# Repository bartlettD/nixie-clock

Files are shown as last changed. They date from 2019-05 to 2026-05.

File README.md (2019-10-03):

# nixie-clock
A Nixie Tube based clock. Because everyone has to play with Nixies once, right?

## Introduction

The goal of this project is to design and contstruct a simple 4/6-Digit clock based around a set of [IN-12B Nixie Tubes](https://en.wikipedia.org/wiki/Nixie_tube). They are a type of cold-cathode display neon readout tube invented in the 1950's and used commonly in the USSR in volume manufacture until the 1980's after the rest of the world had moved on to 7-Segment LED arrays and other indicator technologies.

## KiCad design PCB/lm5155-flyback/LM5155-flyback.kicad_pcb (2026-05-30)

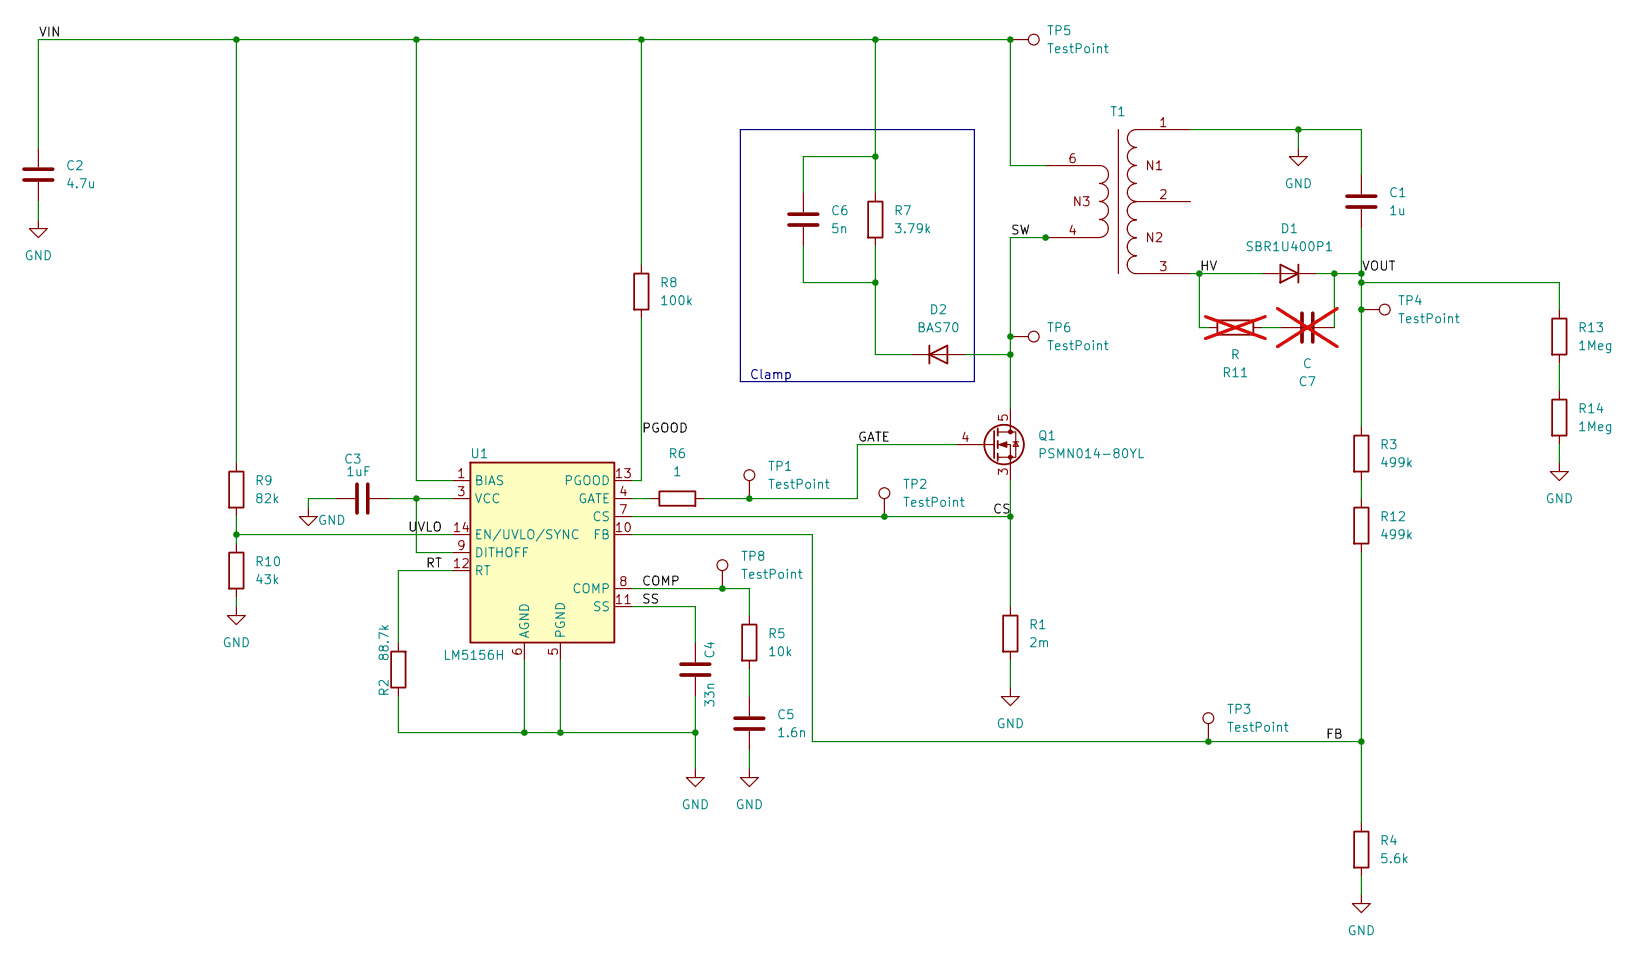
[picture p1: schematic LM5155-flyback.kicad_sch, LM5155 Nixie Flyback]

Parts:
C1: 1u; C_2220_5750Metric_Pad1.97x5.40mm_HandSolder
C2: 4.7u; C_0805_2012Metric_Pad1.18x1.45mm_HandSolder
C3: 1uF; C_0805_2012Metric_Pad1.18x1.45mm_HandSolder
C4: 33n; C_0805_2012Metric_Pad1.18x1.45mm_HandSolder
C5: 1.6n; C_0805_2012Metric_Pad1.18x1.45mm_HandSolder
C6: 5n; C_0805_2012Metric_Pad1.18x1.45mm_HandSolder
C7: C; C_0805_2012Metric_Pad1.18x1.45mm_HandSolder; not fitted
D1: SBR1U400P1; D_PowerDI-123
D2: BAS70; SOT-23
Q1: PSMN014-80YL; LFPAK56
R1: 2m; R_0805_2012Metric_Pad1.20x1.40mm_HandSolder
R2: 88.7k; R_0805_2012Metric_Pad1.20x1.40mm_HandSolder
R3, R12: 499k; R_0805_2012Metric_Pad1.20x1.40mm_HandSolder
R4: 5.6k; R_0805_2012Metric_Pad1.20x1.40mm_HandSolder
R5: 10k; R_0805_2012Metric_Pad1.20x1.40mm_HandSolder
R6: 1; R_0805_2012Metric_Pad1.20x1.40mm_HandSolder
R7: 3.79k; R_0805_2012Metric_Pad1.20x1.40mm_HandSolder
R8: 100k; R_0805_2012Metric_Pad1.20x1.40mm_HandSolder
R9: 82k; R_0805_2012Metric_Pad1.20x1.40mm_HandSolder
R10: 43k; R_0805_2012Metric_Pad1.20x1.40mm_HandSolder
R11: R; R_0805_2012Metric_Pad1.20x1.40mm_HandSolder; not fitted
R13, R14: 1Meg; R_0805_2012Metric_Pad1.20x1.40mm_HandSolder
T1: EP7-5801_750315825; T_Wurth_WE-FLYLT-EP7-5801; Part Number 750315825
TP1, TP2, TP3, TP4, TP5, TP6, TP8: TestPoint; TestPoint_Keystone_5019_Miniature
U1: LM5156H; Texas_HTSSOP-14-1EP_4.4x5mm_P0.65mm_EP3.4x5mm_Mask3.155x3.2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

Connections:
/COMP: R5.1, TP8.1 (1_1), U1.8 (COMP)
/CS: Q1.1 (S), Q1.2 (S), Q1.3 (S), R1.1, TP2.1 (1_1), U1.7 (CS)
/FB: R4.1, R12.2, TP3.1 (1_1), U1.10 (FB)
/GATE: Q1.4 (G), R6.2, TP1.1 (1_1)
/HV: D1.2 (A), R11.1, T1.3
/PGOOD: R8.2, U1.13 (PGOOD)
/RT: R2.2, U1.12 (RT)
/SS: C4.1, U1.11 (SS)
/SW: D2.1 (A), Q1.5 (D), T1.4, TP6.1 (1_1)
/UVLO: R9.2, R10.1, U1.14 (EN/UVLO/SYNC)
/VIN: C2.1, C6.1, R7.1, R8.1, R9.1, T1.6, TP5.1 (1_1), U1.1 (BIAS)
/VOUT: C1.2, C7.1, D1.1 (K), R3.1, R13.1, TP4.1 (1_1)
GND: C1.1, C2.2, C3.1, C4.2, C5.2, R1.2, R2.1, R4.2, R10.2, R14.2, T1.1, U1.5 (PGND), U1.6 (AGND), U1.15 (AGND)
unnamed: C5.1, R5.2
unnamed: C7.2, R11.2
unnamed: C6.2, D2.3 (K), R7.2
unnamed: R3.2, R12.1
unnamed: R13.2, R14.1
unnamed: C3.2, U1.3 (VCC), U1.9 (DITHOFF)
unnamed: R6.1, U1.4 (GATE)

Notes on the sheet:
Clamp

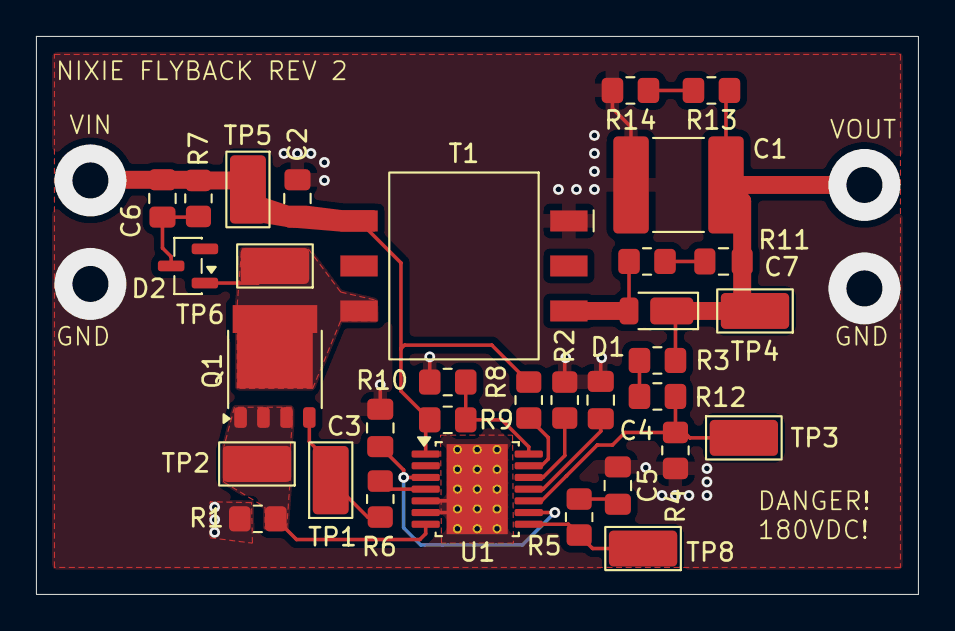
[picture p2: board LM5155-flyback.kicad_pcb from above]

Board: 2 copper layers, 49.0 x 31.0 mm, 33 parts (0 on the bottom side), 20 nets.

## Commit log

2019-05-27 Adding rough simulation of a charge-pump multiplied Boost Circuit
2019-05-27 Starting on PCB, creating IN12-B footprint
    [nixie-clock.kicad_pcb, nixie-clock.sch]
2019-05-28 Add Charge Pump Doubler Simulation
2019-05-29 Improved charge pump circuit
2019-06-03 Introduced Ideal FET and Diode for testing
2019-10-02 Adding spreadsheet to hold calculations for converter
    [BoostCalcs.ods]
2019-10-03 Fixed Symbol library path and Feedback Resistors
    Fixed the LM3478 symbol to point to a .lib within the current directory
    rather than in my own home directory. Makes cloning and running the sims
    on a new computer much easier.
    Fixed the parameter calculation for feedback resistors.
2019-10-03 Doing some calcs for Boost Converter
    [BoostCalcs.ods]
2020-11-12 Work on some Boost Converter calculations
    [BoostCalcs.ods]
2020-11-13 Calculate inductance values vs frequency
    [BoostCalcs.ods]
2020-11-14 Further Boost Converter Calculations
    [BoostCalcs.ods]
2020-11-15 Develop calculation further. Replace ods with fods for better version tracking
    [BoostCalcs.ods]
2020-11-15 Start calculating RMS currents
2020-11-19 Calculate RMS currents for switch, diode, inductor.
2021-07-11 Add simple diode loss calculation
2021-07-13 Inductor resistive losses and calculate total efficieny over inductance vs. frequency
2021-07-24 Trying out sim in KiCad.
    [nixie-clock.sch]
2021-08-08 Add charge pump to Nixie concept
2026-01-13 Rework .gitignore so I can use pspice
    [nixie-clock.kicad_pcb, nixie-clock.sch]
2026-01-13 directory cleanup
    [nixie-clock.kicad_pcb, nixie-clock.sch]
2026-01-15 Flyback pspice simulations
    [flyback.dsn]
2026-01-15 Updated flyback calculations, further flyback simulation
    [flyback.dsn]
2026-01-16 Tidy up FET table
2026-01-17 Add another FET
2026-01-17 TPS40210 converter appears to be working. Still need to properly compensate the control loop
    [flyback.dsn]
2026-01-27 Looking at an LM5155 based converter. Current-mode control is attractive
    [flyback.dsn]
2026-01-28 More simulation. Import WIP LM5155 schematic
    [LM5155-flyback.kicad_pcb, LM5155-flyback.kicad_sch, flyback.dsn]
2026-02-02 Started flyback layout and tweak simulations
    [LM5155-flyback.kicad_pcb, LM5155-flyback.kicad_sch, flyback.dsn]
2026-02-02 More flyback layout. Almost done!
    [LM5155-flyback.kicad_pcb, LM5155-flyback.kicad_sch]
2026-02-03 Layout done. Send to fabricate
    [LM5155-flyback.kicad_pcb]
2026-02-03 Fix small issue with feedback resistors. Hopefully wont cause real issues with Rev 1
    [LM5155-flyback.kicad_pcb, LM5155-flyback.kicad_sch]
2026-05-11 Replaced LM5155 with LM5156H. Also replaced MOSFET. Packages just too difficult to solder.
    [LM5155-flyback-B_Cu.gbr, LM5155-flyback-B_Mask.gbr, LM5155-flyback-B_Paste.gbr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]
2026-05-12 Layout changes
    [LM5155-flyback.kicad_pcb]
2026-05-12 upgrade project to kicad 10
    [LM5155-flyback.kicad_pcb, LM5155-flyback.kicad_sch]
2026-06-04 Accidently used wrong figure for calculating secondary side conduction loss. Currently testing proper sense resistor sizing, completely messed that up!
    [flyback.dsn]
